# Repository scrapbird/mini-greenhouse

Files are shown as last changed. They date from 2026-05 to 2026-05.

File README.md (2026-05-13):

# mini-greenhouse

Greenhouse cabinet for the yard. 2m W × 1.8m H × 0.7m D. Timber frame, polycarbonate cladding, slatted raised floor, double doors, vent hatch in roof.

Plans drafted in **FreeCAD**, with Claude Code assisting via the [`freecad-mcp`](https://github.com/neka-nat/freecad-mcp) MCP server.

See `CLAUDE.md` for locked specs and conventions.

---

## Setup

Target: Ubuntu 25.10. Adapt paths if on another distro.

### 1. Install FreeCAD

Pick one. AppImage is recommended — it's the cleanest way to get current FreeCAD 1.x without snap quirks that complicate the MCP addon path.

**FreeCAD 1.1.1 AppImage** — installed at `~/Software/FreeCAD-1.1.1.AppImage`.

How it was installed:

```bash
mkdir -p ~/Software
wget -O ~/Software/FreeCAD-1.1.1.AppImage \
  https://github.com/FreeCAD/FreeCAD/releases/download/1.1.1/FreeCAD_1.1.1-Linux-x86_64-py311.AppImage
chmod +x ~/Software/FreeCAD-1.1.1.AppImage
```

Run it:

```bash
~/Software/FreeCAD-1.1.1.AppImage
```

Optional — make it launchable from the app menu:

```bash
~/Software/FreeCAD-1.1.1.AppImage --appimage-extract-and-run --install
```

Alternatives (skip — AppImage already done):
- `sudo apt install freecad` — older version, fine if AppImage breaks
- `sudo snap install freecad` — works but uses `~/snap/freecad/common/Mod/` for addons

### 2. Install the `freecad-mcp` addon

```bash
git clone https://github.com/neka-nat/freecad-mcp.git ~/src/freecad-mcp
```

Copy the addon into FreeCAD's `Mod/` directory. Path depends on how you installed FreeCAD:

For our setup (FreeCAD 1.1 AppImage):

```bash
mkdir -p ~/.local/share/FreeCAD/v1-1/Mod/
cp -r ~/src/freecad-mcp/addon/FreeCADMCP ~/.local/share/FreeCAD/v1-1/Mod/
```

Other install methods would use different Mod paths: `~/.FreeCAD/Mod/` for older Ubuntu builds, `~/snap/freecad/common/Mod/` for snap.

Restart FreeCAD. From the Workbench dropdown pick **MCP Addon**, then **Start RPC Server** from the FreeCAD MCP toolbar. Tick **Auto-Start Server** if you want it on every launch.

### 3. `uvx` (Python tool runner)

Already installed on this machine (`/home/user/.local/bin/uvx`). If you ever need it elsewhere:

```bash
curl -LsSf https://astral.sh/uv/install.sh | sh
```

### 4. Wire the MCP server into Claude Code

From the project directory:

```bash
cd ~/Development/mini-greenhouse
claude mcp add freecad -- uvx freecad-mcp
```

This writes a `.mcp.json` in the project so the server is available whenever Claude Code runs here. Verify with:

```bash
claude mcp list
```

FreeCAD must be running with the RPC server started before Claude can talk to it.

### 5. Smoke test

In Claude Code, with FreeCAD open and the RPC server started, ask: *"Create a new FreeCAD document called `greenhouse` and add a 2000×700×1800 box as a placeholder envelope."* If the box appears in FreeCAD, the loop is working.

---

## Repo layout (will fill in as we go)

```
mini-greenhouse/
├── CLAUDE.md           # Specs + conventions for Claude
├── README.md           # This file
├── Greenhouse.FCStd    # FreeCAD model (canonical = closed state)
├── macros/             # FCMacros — open/close toggles
├── notes/              # Cut list + decisions
└── drawings/           # Exported PDFs (later)
```

## Open / close toggle

Two macros in `macros/` toggle the doors + roof hatch between closed and open states. They read all geometry from the `Dims` spreadsheet, so they stay in sync if you change posts/depth/etc.

- `gh_open.FCMacro` — swings doors out 90°, lifts hatch 60°, deploys the prop
- `gh_close.FCMacro` — reverses all of the above

To make them appear in FreeCAD's **Macro → Macros…** menu, symlink them into FreeCAD's macro dir:

```bash
ln -s ~/Development/mini-greenhouse/macros/gh_open.FCMacro ~/.local/share/FreeCAD/Macro/
ln -s ~/Development/mini-greenhouse/macros/gh_close.FCMacro ~/.local/share/FreeCAD/Macro/
```

Then in FreeCAD: **Macro → Macros…**, pick one, Execute. Or run via the FreeCAD Python console:

```python
exec(open("/home/user/Development/mini-greenhouse/macros/gh_open.FCMacro").read())
```

Macros are idempotent — running `gh_open` twice is a no-op (it detects the `Hatch_Prop` object).

---

---

## Materials

Prices NZD, rough Mitre 10 NZ ballparks — Mitre 10 NZ doesn't publish online pricing; confirm in-store.

> **Future Claude: foundation (pavers + sand) is NOT in the build budget — sourced separately. Do not add it back to subtotals or "Total estimate". Foam profile fillers for the corrugated roof are also out — the user doesn't need an airtight roof. Don't reintroduce them.**

Detailed cut list with per-product links: see [notes/cut-list.md](notes/cut-list.md).

### Timber

H3 = above-ground outdoor treated. H4 = ground-contact treated. Treated radiata pine: cheap, everywhere, rated for outdoor weather, takes stain well.

| Use | Stock | Why |
|---|---|---|
| 4× corner posts | **70×45 H3 SG8 KD pine** | Carries shelf loads + door weight. 70mm depth gives hinge screws bite. |
| Frame rails, rafters, door frames, shelf battens, back centre beam | **70×35 H3 SG8 pine** | Cheaper + lighter than 70×45. Plenty for this span. |
| Floor bearers (under cabinet, on pavers) | **90×45 H4 wet SG8 pine** | Ground-contact — first thing to rot if you skimp. |
| Floor slats + shelf slats | **90×21 H3 radiata decking** | Pre-milled smooth top, wet-duty rated. (Mitre 10 NZ stock is 90×21, not 90×19.) |

Qty + cost (2.4m lengths):

- 4× 70×45 H3 → ~$64
- 18× 70×35 H3 → ~$198
- 2× 90×45 H4 → ~$40
- 12× 90×21 decking → ~$216

**Timber subtotal: ~$518**

Why higher than first sketch: pallet-style shelves use 4 long 70×35 battens + 28 short 90×21 slats. That alone is ~9 extra lengths of timber.

### Polycarbonate

| Type | Pros | Cons | Best use |
|---|---|---|---|
| **Corrugated (Sunclear / Suntuf)** | Cheap, purpose-built for roofing, sheds water naturally, easy to screw with cap screws | Profile only suits roofs/walls with same profile; needs foam closure under ridges | **Roof** ✓ |
| **Twinwall (Ampelite, 6mm)** | Insulating air gap = warmer greenhouse, light-diffusing, externally flat, cheaper than solid | Channels need taping/closing at cut ends; not crystal-clear | **Sides + back + doors** ✓ |
| **Solid clear sheet (2–3mm)** | Crystal-clear, premium look | ~2× price of twinwall, no insulation, scratches show | Skip for this build |

Recommendation: **corrugated roof + twinwall everywhere else.**

- 1× Sunclear corrugated 2.4m clear → ~$40
- 2× Ampelite twinwall 1050×2500mm clear (back + side + door panels cut from these) → ~$140
- Aluminium U-channel edging (3 × 1m) for cut twinwall ends → ~$25

**Polycarbonate subtotal: ~$205**

### Foundation (sourced separately, NOT in build budget)

**6× 400×400×40mm concrete pavers, levelled on a sand bed, with H4 bearers spanning across them.**

- Cheap, no concreting, fully removable
- Lifts timber clear of wet ground
- Forgiving of slight ground unevenness — just rake sand flat
- Footprint: pavers overhang cabinet front and back by ~178mm each side (front overhang doubles as a doorstep)

Skip: concrete piers (overkill, permanent), galvanised post stirrups (overkill, $$$), direct-on-ground (rot bomb).

- 6× 400×400 pavers @ ~$8 → ~$48
- 1× paving sand 20kg → ~$8

*Excluded from build cost — user is sourcing pavers + sand separately.*

### Door hardware

Pattern: **inactive door (left) bolted top+bottom**, acts as a fixed jamb when shut. **Active door (right) latches** against the inactive leaf's astragal. Astragal strip on inactive leaf seals the meeting edge.

| Item | Count | Price |
|---|---|---|
| Tee-hinges, 150mm galvanised (face-mount, no rebating) | 3 per leaf × 2 = 6 | ~$108 |
| 100mm barrel bolts (inactive leaf top + bottom into roof frame and floor) | 2 | ~$30 |
| D-type gate latch (active leaf) | 1 | ~$18 |
| Handles | 2 | ~$10 (or $0 if drilled finger-pulls) |

**Door hardware subtotal: ~$166**

### Hatch hardware

Hatch hinges along the back ridge, lifts at front. Two hook-and-eye latches at front-left and front-right pin it shut against wind lift. A telescopic window stay holds it open at multiple angles.

| Item | Count | Price |
|---|---|---|
| Butt hinges 50mm zinc — corner+corner+middle along back ridge | 3 (buy 2× 2-pack) | ~$20 |
| Hook & eye latches 100mm (2-pack) | 1 pack | ~$10 |
| Telescopic window stay (multi-position) | 1 | ~$20 |

**Hatch hardware subtotal: ~$50**

### Fasteners

- Otter Treated Pine Screws 10g × 65mm, pack of 500 (frame joints — must be treated-pine rated for H3/H4 stock) → ~$45
- Otter Heavy Duty Timber Screws 14g × 50mm, pack of 100 (slats, trims) → ~$22
- Otter Polycarbonate Roof Screws 12g × 50mm, pack of 50 → ~$25
- 4–6× Zenith corner brace brackets, zinc plated → ~$25
- Aluminium U-channel 20×20×1.5mm × 2.4m (twinwall edges) → ~$25

**Fasteners subtotal: ~$142**

### Finish

Water-based decking stain (DECKMAX or Wattyl — Cabot's range is limited at Mitre 10 NZ). Apply two coats after assembly, before fitting polycarbonate.

- 10L water-based decking stain — Honey Oak or similar dark tone → ~$100 (overkill for this build; if 5L sold in-store, halve)
- Brushes (75mm + small) → ~$15

**Finish subtotal: ~$115**

### Shelves

**Timber cleats** screwed into the inner faces of the side walls — one continuous batten per height per side, shelf sits on top. 5 height positions, first at 475mm from frame bottom, 175mm spacing (last at 1175mm). 2 pallet-style shelves fitted at positions 3 and 5; can be moved.

Cleats: 20×15mm offcuts of 70×35 stock, full depth (560mm). 10 cleats total → free from frame offcuts.

Each shelf: 2× 70×35 cross-battens (1910mm long) + 14× 90×21 decking slats (560mm each) screwed on top with ~50mm gaps. Drains like the floor.

**Shelf cost: ~$0** beyond timber already counted.

### Total estimate

| | NZD |
|---|---|
| Timber | 518 |
| Polycarbonate | 205 |
| Door hardware | 166 |
| Hatch hardware | 50 |
| Fasteners | 142 |
| Finish | 115 |
| **Subtotal** | **~$1,196** |

Foundation (~$56) sourced separately, not in this subtotal. Levers to claw back, with quantified savings and running build cost if applied in order:

| # | Lever | Saves | Build cost after |
|---|---|---|---|
| 0 | (baseline) | — | $1,196 |
| 1 | Drop to 1 shelf (2 fewer battens @ ~$11 + 14 fewer decking slats @ ~$5.20) | $95 | $1,101 |
| 2 | 5L stain instead of 10L | $50 | $1,051 |
| 3 | Untreated pine for shelf slats (under roof, less weather) | $60 | $991 |
| 4 | Corrugated for back panel (replace twinwall sheet) | $50 | $941 |
| 5 | Skip aluminium U-channel; foil-tape twinwall ends + timber trim | $25 | $916 |
| 6 | Mix Marketplace / TradeMe offcuts for posts + bearers | $80+ | $836 |

Realistic floor with all levers applied: **~$836 NZD** (materials only).

---

## Tools

Detailed list with prices + ALoT (Auckland Library of Tools) borrow plan: see [tools.md](tools.md).

Owned: hand saw, cordless drill. Buying only consumables + PPE + a few daily-use measuring tools. Borrowing everything else (router, pocket-hole jig, circular saw, mitre saw, sander, clamps, levels, workbench) from ALoT half-yearly membership ($60).

| Path | NZ$ |
|---|---|
| **Borrow-max:** must-buy ($205) + ALoT half-year ($65) | **~$270** |
| + keep pocket-hole jig | ~$350 |
| + keep jig + router | ~$500 |

Default for grand total below: **borrow-max ~$270**.

Skills + YouTube tutorials: see [study_guide.md](study_guide.md).

---

## Grand total (materials + tools)

| | NZD |
|---|---|
| Materials | ~$1,196 |
| Tools (borrow-max — see Tools section) | ~$270 |
| **Project total** | **~$1,466** |

Foundation (pavers + sand, ~$56) sourced separately — not included.

Other tool paths shift the total: + jig keep = ~$1,546, + jig + router keep = ~$1,696.

With all material levers applied (see Materials → Total estimate) + borrow-max tools: could land **~$1,106 all-in** ($836 materials + $270 tools).

---

## Open questions

Still need a call on:

- Pre-stain timber before assembly, or after? (before = no missed spots; after = easier touchup)
- Floor anchoring method — depends on final site (lawn / paver / concrete)
- Stop-grooves (stub tenon) vs through-grooves on door rails — practise both, pick easier
- Future woodworking projects? — decides whether to keep (buy) jig + router (+$275) vs return after build

Resolved:

- ~~Site orientation~~ → doors face afternoon sun (west)
- ~~Tools: buy vs borrow~~ → borrow-max via ALoT half-yearly; revisit jig/router purchase if used after this build
- ~~Door panel join~~ → routed grooves (router borrowed from ALoT)

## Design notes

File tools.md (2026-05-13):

# Tools — Mitre 10 NZ + ALoT

All prices NZD, mitre10.co.nz as of 2026-05-12. Confirm at checkout.

**You already own:** hand saw, cordless drill.

Strategy: **only buy** consumables, PPE, and the few tools you'll use every day. **Borrow everything else from ALoT** — including router and pocket-hole jig if you'd only use them on this project.

---

## Already owned — skip

- Hand saw
- Cordless drill

---

## Must buy — non-borrowable

Personal/consumable items you can't (or shouldn't) share.

| Tool | Pick | NZ$ | Why must-buy |
|---|---|---|---|
| Pocket-hole screws (mixed 32+38mm) | Fuller 200-pack | $30 | Consumable |
| Drill bit set HSS | Bosch HSS 19pc 1–10mm | $45 | Personal kit, wears |
| Pozi driver bits + spares | mixed pack | $10 | Wears |
| Counter-sink bit | Stanley | $15 | Small, wears |
| Tape measure 8m | Stanley Tylon 8m | $17 | Daily use, yours |
| Combination square 300mm | Number 8 | $10 | Daily use, cheap |
| Pencils + marker + utility knife | Stanley | $20 | Daily / consumable |
| Safety glasses | Esko clear | $8 | PPE, fit/hygiene |
| Dust mask P2 (5-pack) | 3M 8210 | $25 | PPE, consumable |
| Hearing protection | Safety Extra earmuffs | $25 | PPE, fit/hygiene |

**Must-buy subtotal: ~$205**

---

## Optional buys — keep long-term, or borrow

| Tool | If buying NZ$ | Decision |
|---|---|---|
| Pocket-hole jig (Fuller, M10) | $80 | Buy if you'll do more woodworking. Otherwise borrow from ALoT |
| Router 1/4" + 6mm straight + slot bit | $150 (Ryobi + bits) | Same — buy if keeper, borrow if one-off |
| Bar clamps 300mm × 2 (cheap pair) | $45 | Buy 2 cheap, borrow extras from ALoT |

**If buying all three: +$275.**

---

## Borrow from ALoT 🅑

All borrowable; ALoT membership covers them.

| Tool | If buying NZ$ |
|---|---|
| 🅑 Circular saw 165mm | $60–280 |
| 🅑 Sliding compound mitre saw | $250 |
| 🅑 Random orbital sander | $80 |
| 🅑 Router + bits | $150 |
| 🅑 Pocket-hole jig | $80 |
| 🅑 Bar clamps (3+) | $60+ |
| 🅑 Spirit level 600mm | $16 |
| 🅑 Speed square / rafter square | $20 |
| 🅑 Bevel gauge / sliding T-bevel | $25 |
| 🅑 Long straight edge 1.2m+ | $30 |
| 🅑 Workbench / Workmate | $120 |
| 🅑 Sawhorses × 2 | $100 |

**Total avoided buys if you borrow all: ~$990+** — well worth the $60 membership.

> Verify ALoT inventory before joining. Browse: https://aucklandlibraryoftools.myturn.com/

---

## Consumables (already in materials budget — listed for completeness)

| Item | NZ$ |
|---|---|
| Cap screws + EPDM washers — corrugated poly (50-pack) | ~$25 |
| Cap screws + neoprene washers — twinwall (50-pack) | ~$25 |
| Aluminium U-channel for twinwall bottom edge (per m) | ~$8/m |
| Breathable foil tape for twinwall top edge (10m roll) | ~$30 |
| Stainless 8g×50 screws (200-pack) | ~$25 |
| Stainless 8g×75 screws (100-pack) | ~$25 |
| Exterior wood glue (Selleys Aquadhere Exterior 250ml) | ~$15 |
| Outdoor timber oil (4L) | ~$60 |
| Brushes (2-pack 50mm) | ~$10 |

---

## Auckland Library of Tools (ALoT)

**Address:** Newton/Grey Lynn, Auckland. **Site:** https://www.aucklandlibraryoftools.com/

**Membership:**

| Tier | Regular | Concession (student/CSC/gold card) |
|---|---|---|
| Monthly | $45 | $30 |
| Half-yearly | $60 | $45 |
| Annual | $105 | $75 |

**How it works:**
- Up to **10 tools at a time**
- Default loan: **7 days** (4 days on high-demand items)
- Most tools free with membership; some small per-loan charge
- Battery tools: +$1/loan
- Volunteer-run, non-profit, since 2019
- Browse inventory: https://aucklandlibraryoftools.myturn.com/

**Recommended path for this build:**
1. **Half-yearly $60** covers build window with slack.
2. Pre-check inventory online (router + jig + circular saw + mitre saw + sander + clamps).
3. Plan ALoT trips in batches — 10 tools per loan, 7 days each.

---

## Three honest tool-spend paths

| Path | What you buy | NZ$ |
|---|---|---|
| **Borrow-max** | Must-buy ($205) + ALoT half-year ($60 + ~$5 loan fees) | **~$270** |
| **+ keep jig** | Above + pocket-hole jig ($80) | **~$350** |
| **+ keep jig + router** | Above + Ryobi router ($150) | **~$500** |

Recommended: **borrow-max ~$270** unless you know you'll do more woodworking. Router + jig are the two biggest line items and both are well-stocked at ALoT.

---

## Where to shop

- **Mitre 10 NZ:** https://www.mitre10.co.nz/
- **Bunnings NZ:** https://www.bunnings.co.nz/ — Kreg jigs stocked here
- **Facebook Marketplace / TradeMe** — used drill kits, clamps
- **Hireace / Hirepool** — backup if ALoT doesn't have what you need
- **ALoT** — see above

---

## Open questions (tools-side)

- Borrow router + jig (~$270 total path) **or** buy them for future projects (~$500 total)? Depends on what comes after this build

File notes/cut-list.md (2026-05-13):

# Cut list

Generated from FreeCAD model. Bin-packed at 2.4m stock lengths, 3mm kerf per cut.

Product links → Mitre 10 NZ (mitre10.co.nz). Prices are NZD estimates only — Mitre 10 NZ doesn't publish online pricing; confirm at your local store.

## Stock summary

| Stock | Pieces | 2.4m lengths | Est. price/length | Subtotal |
|---|---|---|---|---|
| 70×45 H3 SG8 KD pine (posts) | 4 | 4 | ~$16 | ~$64 |
| 70×35 H3 SG8 KD pine (frame/doors/shelves/roof) | 27 | 18 | ~$11 | ~$198 |
| 90×45 H4 wet SG8 pine (floor bearers) | 2 | 2 | ~$20 | ~$40 |
| 90×21 H3 radiata decking (floor + shelf slats) | 33 | 12 | ~$18 | ~$216 |

**Timber subtotal: ~$518 NZD**

Cleats + astragal: rip from 70×35 offcuts (no extra stock). Decking is 90×21 at Mitre 10 NZ (closest to model's 90×19 — 2mm thicker, negligible).

## 70×45 H3 SG8 KD pine — [Mitre 10 product](https://www.mitre10.co.nz/shop/building-hardware/timber/structural-framing/structural-framing/radiata-sg8-h3-kd-70x45mm-140x45mm/c/RC61070)

| Piece | Length |
|---|---|
| Frame_PostBL | 1719mm |
| Frame_PostBR | 1719mm |
| Frame_PostFL | 1569mm |
| Frame_PostFR | 1569mm |

**4 pieces, 4 × 2.4m lengths** (1 post per length).

## 70×35 H3 SG8 pine — [Mitre 10 timber category](https://www.mitre10.co.nz/shop/building-hardware/timber/structural-framing/c/RS4105)

| Piece | Length | Count |
|---|---|---|
| Frame_EaveFront | 1930mm | 1 |
| Frame_RailBot{Front,Back}, Frame_RailTopFront, Frame_RailTopBack | 1910mm | 4 |
| Frame_RidgeBack | 1930mm | 1 |
| Shelf{2,3}_Batten{Front,Back} | 1910mm | 4 |
| Frame_BackCenter | 1700mm | 1 |
| Door{L,R}_Stile{Hinge,Latch} | 1426mm | 4 |
| Door{L,R}_Rail{Top,Bot} | 882mm | 4 |
| Frame_Rafter{Left,Right,Center} | 838mm | 3 |
| Frame_RailTop{Left,Right} | 573mm | 2 |
| Frame_RailBot{Left,Right} | 560mm | 2 |
| Frame_FloorCenter | 630mm | 1 |

**27 pieces, 18 × 2.4m lengths.**

Packing:
- 2 × (1930 + 470 offcut) — eave purlin + ridge purlin
- 8 × (1910 + 490 offcut) — perimeter rails + shelf battens
- 1 × (1700 + 573 + 127 offcut)
- 4 × (1426 + 882 + 92 offcut)
- 1 × (838 + 838 + 560 + 164 offcut) — rafters L+R + side bot rail
- 1 × (838 + 630 + 573 + 359 offcut) — **rafter Center + floor centre + side top rail**
- 1 × (560 + 1840 offcut) — side bot rail #2 (large offcut → cleats/astragal stock)

## 90×45 H4 wet SG8 pine — [Mitre 10 product](https://www.mitre10.co.nz/shop/building-hardware/timber/structural-framing/structural-framing/wet-radiata-sg8-h4-90x45mm/c/RC61520)

| Piece | Length |
|---|---|
| Foundation_BearerFront | 2000mm |
| Foundation_BearerBack | 2000mm |

**2 pieces, 2 × 2.4m lengths.**

## 90×21 H3 radiata decking — [Radiata Premium Grade Smooth Decking 90 × 21mm](https://www.mitre10.co.nz/shop/radiata-premium-grade-smooth-decking-90-x-21mm/p/635401)

| Piece | Length | Count |
|---|---|---|
| Floor_Slat{1..5} | 1930mm | 5 |
| Shelf{2,3}_Slat{01..14} | 560mm | 28 |

**33 pieces, 12 × 2.4m lengths.**

Packing:
- 5 × (1930 + 470 offcut)
- 7 × (4 × 560 + 151 offcut)

## From offcuts (no extra stock)

- **10 × shelf cleats** @ 560mm × 20×15mm — rip from 70×35 offcuts (~6m of cleat needed; one 2.4m of 70×35 ripped yields ~14m of 20×15 strips)
- **1 × astragal** @ 1497mm × 30×12mm — rip from a 1910 offcut

# Polycarbonate panels

| Panel | W × H (mm) | Buy product |
|---|---|---|
| Roof_Hatch | 2000 × 822 | [Sunclear Ultra Corrugated 2.4m Clear](https://www.mitre10.co.nz/shop/sunclear-ultra-corrugated-polycarbonate-2-4m-clear/p/335668) (cut to 822mm width from 860mm sheet) |
| Panel_BackL, Panel_BackR | 1630 × 930 | [Ampelite Twinwall Glazing 1050 × 2500mm Clear](https://www.mitre10.co.nz/shop/ampelite-twinwall-polycarbonate-glazing-system-1050-x-2500mm-clear/p/128788) (one sheet cuts two back panels) |
| Panel_Left, Panel_Right | 1650 × 630 | Cut from the same back-panel sheet's offcut, or [Ampelite 1220 × 610mm Clear](https://www.mitre10.co.nz/shop/ampelite-twinwall-polycarbonate-sheet-1220mm-x-610mm-clear/p/286867) (×2 — but undersize, would need larger) |
| DoorL_Infill, DoorR_Infill | 1427 × 882 | Cut from a 1050 × 2500mm sheet (1 more sheet needed) |

**Polycarb estimate**:
- 1 × Sunclear corrugated 2.4m: ~$40
- 2 × Ampelite twinwall 1050×2500: ~$70 each = ~$140
- Total: ~**$180 NZD**

Side panels are 5-sided: cut as rectangle, then trim the upper edge to follow roof slope (~12° from horizontal).

# Hardware

## Door hardware

| Item | Count | Product | Est. NZD |
|---|---|---|---|
| Tee-hinges (face-mount on front) | 3 per door × 2 doors = 6 | [Gator Heavy Duty Tee Hinge 150mm Galvanised](https://www.mitre10.co.nz/shop/gator-heavy-duty-tee-hinge-150mm-galvanised/p/384426) | ~$18 each → ~$108 (or buy 2-packs if cheaper per-unit) |
| 100mm barrel bolts (inactive leaf top + bottom) | 2 | [Zenith Necked Barrel Bolt 100mm](https://www.mitre10.co.nz/shop/zenith-necked-barrel-bolt-100mm/p/205383) | ~$15 each → ~$30 |
| Gate latch (active leaf) | 1 | [Gartner D Type Gate Latch 170mm Galvanised](https://www.mitre10.co.nz/shop/gartner-d-type-gate-latch-170mm-galvanised/p/374863) | ~$18 |
| Cabinet pulls / handles | 2 | Generic pull or drilled finger-pull | ~$10 (or $0 if drilled) |

## Hatch hardware

| Item | Count | Product | Est. NZD |
|---|---|---|---|
| Butt hinges (back ridge — corner+corner+middle) | 3 (buy 2× 2-pack) | [Zenith Easy Fit Hinges 50mm Zinc Plated](https://www.mitre10.co.nz/shop/zenith-easy-fit-hinges-50mm-zinc-plated/p/209101) | ~$20 (2× 2-pack) |
| Casement window stay (multi-position) | 1 | [Jaeco Telescopic Window Stay 278mm](https://www.mitre10.co.nz/shop/jaeco-telescopic-window-stay-278mm-satin-chrome-finish/p/214252) | ~$20 |
| Hook & eye latches (front corners) | 2 | [Zenith Gate Hook & Eye 100mm — 2 Pack](https://www.mitre10.co.nz/shop/zenith-gate-hook-eye-zinc-plated-100mm-2-pack) | ~$10 (2-pack covers both) |

## Foundation (sourced separately — NOT in build budget)

| Item | Count | Product | Est. NZD |
|---|---|---|---|
| 400×400×40mm concrete pavers | 6 | [Premier Flagstone Paver 400×400×40mm](https://www.mitre10.co.nz/shop/premier-flagstone-paver-400-x-400-x-40mm-iron-sand/p/202882) | ~$8 each → ~$48 |
| Paving sand | 1 bag | [Paving Sand 20kg](https://www.mitre10.co.nz/shop/paving-sand-20kg/p/2023381) | ~$8 |

*Future Claude: don't add this to subtotals — user sources separately.*

## Fasteners

| Item | Pack | Product | Est. NZD |
|---|---|---|---|
| 65mm timber screws (frame) | 1 pack (~100 needed) | [Otter Treated Pine Screws 10g × 65mm — Pack of 500](https://www.mitre10.co.nz/shop/otter-treated-pine-screws-10g-x-65mm-pack-of-500-galvanised/p/327993) (treated-pine rated, important for H3/H4 stock) | ~$45 |
| 50mm timber screws (slats, trims) | 1 pack (~50 needed) | [Otter Heavy Duty Timber Screws 14g × 50mm — Pack of 100](https://www.mitre10.co.nz/shop/otter-heavy-duty-timber-screws-14g-x-50mm-pack-of-100-galvanised/p/231194) | ~$22 |
| Polycarbonate roof screws | 1 pack (~40 needed) | [Otter Polycarbonate Roof Screws 12g × 50mm — Pack of 50](https://www.mitre10.co.nz/shop/otter-polycarbonate-roof-screws-12g-x-50mm-pack-of-50-galvanised/p/231773) | ~$25 |
| Corner brace brackets | 4–6 | [Zenith Corner Brace Bracket](https://www.mitre10.co.nz/shop/zenith-corner-brace-bracket/p/220106) | ~$5 each → ~$25 |
| Aluminium U-channel (twinwall edges) | 3 × 1m or 1 × 2.4m | [Metal Mate Aluminium Channel 20 × 20 × 1.5mm × 2.4m](https://www.mitre10.co.nz/shop/metal-mate-aluminium-channel-20x20x1-5mm-x-2-4m-silver/p/372583) | ~$25 |

**Fasteners subtotal: ~$142 NZD**

*Future Claude: foam eave filler under corrugations is intentionally excluded — user doesn't need an airtight roof. Don't add it back.*

## Finish

| Item | Size | Product | Est. NZD |
|---|---|---|---|
| Water-based decking stain | 10L | [Water Based Decking Stain 10L Honey Oak](https://www.mitre10.co.nz/shop/water-based-decking-stain-10l-honey-oak/p/278680) (10L is overkill — confirm if 5L sold in-store) | ~$100 |
| Brushes (75mm + small) | — | Generic brushes | ~$15 |

**Finish subtotal: ~$115 NZD**

# Total estimate (NZD)

| | NZD |
|---|---|
| Timber | 518 |
| Polycarbonate | 205 |
| Door hardware | 166 |
| Hatch hardware | 50 |
| Fasteners | 142 |
| Finish | 115 |
| **Subtotal** | **~$1,196** |

Foundation (~$56 in pavers + sand) sourced separately, **not** in this subtotal. Foam roof eave filler also excluded — user doesn't need an airtight roof.
- README under-counted hardware (tee-hinges, stay, brackets).

Levers to claw back:
- Drop one shelf (already at 2; could go to 1 to halve shelf timber).
- Use 90×19 untreated for shelf slats, finished with stain (cheaper, less rot-resistant — OK if shelves don't see direct rain).
- Buy 5L stain, not 10L (~$50 saved).
- Use smaller polycarb sheet sizes — e.g. corrugated for the back too (cheaper than twinwall).

# Joinery summary

All joints butt + screw. No mortice/tenon, no halving. Pocket screws optional for door frames if a Kreg jig is borrowable.

Critical joint locations:
- Posts ↔ bottom rails: 2 × 65mm screws toe-nailed through rail end into post end-grain. Add corner brace.
- Posts ↔ top rails: same.
- Top rails ↔ rafters: rafters sit on top of front + back top rails. 2 screws each end through rafter into rail.
- Door frame stiles ↔ rails: pocket screws (preferred) OR 2 × 65mm through stile face into rail end. Glue.
- Bearers ↔ bottom rails: 4–5 × 65mm screws up through bearer into bottom rail.
- Centre back beam ↔ top/bottom rails: butt + 2 × 65mm screws each end.
- Cleats ↔ side panels/posts: 3 × 50mm screws per cleat through side panel into post (front+back+middle).
- Tee-hinges: through hinge plate into door stile (front face) + post (front face).

# Sources

- [Pine Products at Mitre 10](https://www.mitre10.co.nz/trade/suppliers/pine-products)
- [Mitre 10 timber category](https://www.mitre10.co.nz/shop/building-hardware/timber/c/RD1001)
- [Mitre 10 structural framing](https://www.mitre10.co.nz/shop/building-hardware/timber/structural-framing/c/RS4105)
- [Mitre 10 decking timber](https://www.mitre10.co.nz/shop/building-hardware/timber/decking-timber/c/RS4108)
- [Mitre 10 roofing polycarbonate](https://www.mitre10.co.nz/shop/building-hardware/building-supplies/roofing/roofing/roofing-polycarbonate/c/RC42630)
- [Mitre 10 pavers & blocks](https://www.mitre10.co.nz/shop/building-supplies/concrete-metal-products/pavers-blocks/c/RF5051)
- [Mitre 10 hinges](https://www.mitre10.co.nz/shop/building-hardware/hardware/gate-fence-hardware/hinges/c/RF7146)
- [Mitre 10 window stays](https://www.mitre10.co.nz/shop/building-hardware/hardware/windows/window-stays/c/RF7395)
- [Mitre 10 fasteners](https://www.mitre10.co.nz/shop/building-hardware/hardware/fasteners-fixing/screws/general-timber-screws/c/RC19300)
- [Mitre 10 exterior stains & oils](https://www.mitre10.co.nz/shop/paint-decorating/paint/exterior-paint/exterior-stains-oils/c/RF7097)

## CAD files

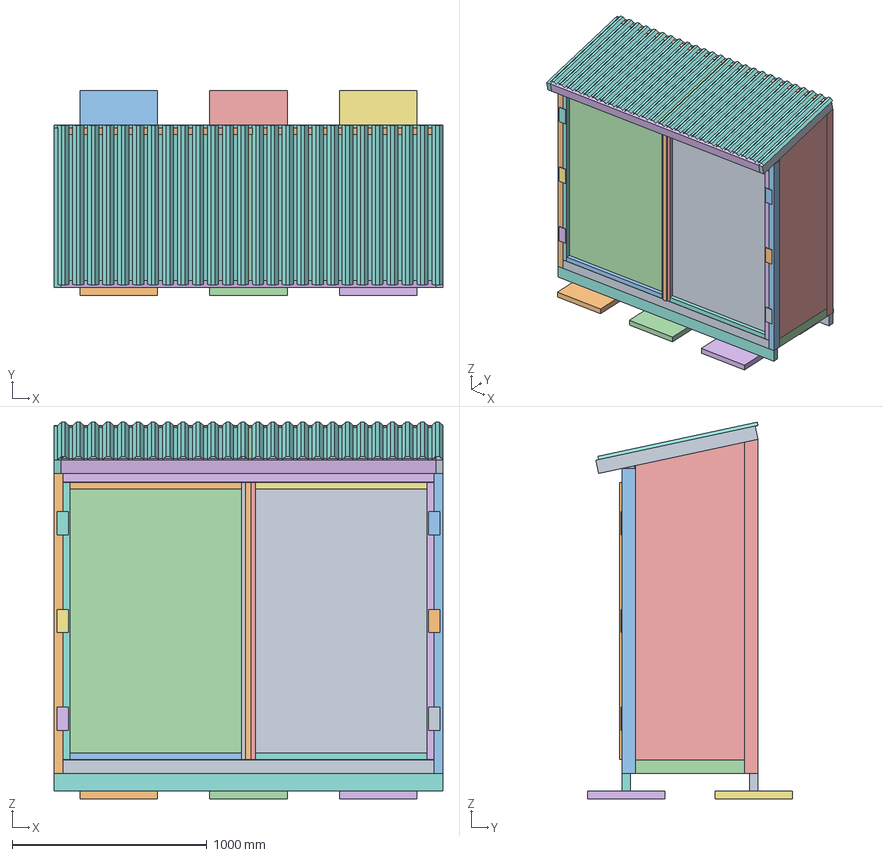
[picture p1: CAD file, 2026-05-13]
Greenhouse.FCStd
2000.0 x 1055.0 x 1936.8 mm
Frame_RailBotFront
Frame_RailBotBack
Frame_RailBotLeft
Frame_RailBotRight
Shelf_CleatL2
Shelf_CleatR2
Shelf_CleatL3
Shelf_CleatR3
Shelf_CleatL4
Shelf_CleatR4
Shelf_CleatL5
Shelf_CleatR5
Shelf_CleatL6
Shelf_CleatR6
Hatch_LatchL
Hatch_LatchR
Shelf2_BattenFront
Shelf2_BattenBack
Shelf2_Slat01
Shelf2_Slat02
Shelf2_Slat03
Shelf2_Slat04
Shelf2_Slat05
Shelf2_Slat07
Shelf2_Slat08
Shelf2_Slat09
Shelf2_Slat10
Shelf2_Slat11
Shelf2_Slat12
Shelf2_Slat13
Shelf2_Slat14
Foundation_BearerFront
Foundation_BearerBack
Foundation_Paver1F
Foundation_Paver1B
Foundation_Paver2F
Foundation_Paver2B
Foundation_Paver3F
Foundation_Paver3B
Roof_Hatch
Shelf3_BattenFront
Shelf3_BattenBack
Shelf3_Slat01
Shelf3_Slat02
Shelf3_Slat03
Shelf3_Slat04
Shelf3_Slat05
Shelf3_Slat06
Shelf3_Slat07
Shelf3_Slat08
Shelf3_Slat09
Shelf3_Slat10
Shelf3_Slat11
Shelf3_Slat12
Shelf3_Slat13
Shelf3_Slat14
Floor_Slat1
Floor_Slat2
Floor_Slat3
Floor_Slat4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

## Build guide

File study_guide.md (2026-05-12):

# Study guide — mini-greenhouse build

Skills you'll touch, in roughly the order you need them. Each entry: what, why, links.

---

## 1. Measure & mark

What: pull tape, transfer dim to timber, mark cut line with square + pencil. "Measure twice, cut once" is real.

Why: every cut later inherits the error from this step.

Watch:
- [Tape measure tips for beginners](https://www.youtube.com/watch?v=Ifk7Bn5Vluc) — reading 16ths, hook is loose on purpose
- [Using a combination square](https://www.youtube.com/watch?v=2hkqe_VFOR0) — square line, mitre, marking depth

---

## 2. Crosscuts (square cuts to length)

What: 90° cut across timber. Most cuts on this build are crosscuts to length.

Tools: hand saw OR circular saw with speed square as guide.

Why: posts, rails, slats — all crosscut.

Watch:
- [Circular saw basics (beginner)](https://www.youtube.com/watch?v=R4ApY7lFqEM)
- [Using a speed square as a cut guide](https://www.youtube.com/watch?v=K8GG8FXxnGw)
- [Hand saw technique](https://www.youtube.com/watch?v=4iJKBYNJxqM) — if going manual

Tip: clamp a straight board as a fence — gives perfectly square cuts every time with circular saw.

---

## 3. Bevel cuts

What: cut with the blade tilted, not perpendicular. Used for side top rails (≈12° bevel to match roof slope) and rafter ends.

Why: side top rails need vertical ends so they sit flush against the vertical posts, but their face is sloped. So the end-cut is a bevel.

Watch:
- [Bevel cuts with a circular saw — Mr Adams](https://www.youtube.com/watch?v=gVq9n-JTowY)
- [Toolstop bevel guide](https://www.youtube.com/watch?v=veinzkhZBCA)
- [45° bevel + miter explained](https://www.youtube.com/watch?v=znQvM59Xt3c)

Tip: set the angle, cut a test piece, check with a protractor or bevel gauge before cutting your real timber.

---

## 4. Pocket-hole joinery ← **chosen method for this build**

What: drill an angled hole into one board, drive a screw through it into the next board. Strong, hidden, beginner-friendly.

Why: joining rails to posts and door-frame stiles to rails. Faster than mortise & tenon, stronger than butt-screws.

Watch:
- [Beginner's guide to pocket holes (Kreg)](https://www.youtube.com/watch?v=eLrDC0xYzQU)
- [Pocket-hole tutorial 320 jig](https://www.youtube.com/watch?v=4cGzVCcDDZA)
- [Pocket Holes 101 step-by-step](https://www.youtube.com/watch?v=bxRSbg8WAz4)
- [Kreg official "7 simple pocket-hole joints"](https://learn.kregtool.com/learn/video-7-simple-pocket-hole-joints/)

For this build: 70×45 posts and 70×35 rails — use coarse-thread screws (softwood), set jig for 35mm material thickness.

---

## 5. Drilling pilot holes

What: small-diameter hole before driving screw — prevents splitting, keeps screw straight.

Why: timber will split when screwing close to an end. Always pilot near ends, near edges, into hardwood, or with fat screws.

Watch:
- [Pilot holes — when and why](https://www.youtube.com/watch?v=qPB1aPAItuQ)

Rule of thumb: pilot ≈ 70% of screw shank diameter (so for an 8g screw ≈ 3mm bit).

---

## 6. Router work — grooved door panels ← **chosen for this build**

What: cut a groove down the inside edge of each door stile + rail so a poly panel slides in like a picture frame. Done with a plunge router + straight bit (6mm matches twinwall thickness).

Why: strong, weatherproof door without exposed fasteners on the panel. The look you wanted.

Watch:
- [Router basics — plunge router intro](https://www.youtube.com/watch?v=lXJ5rOzGoa4)
- [Cabinet door with grooved frame (router)](https://www.youtube.com/watch?v=u3qzWg8Yj-c)
- [Cutting a groove with a router & edge guide](https://www.youtube.com/watch?v=O_Lk5n3LXYM)
- [Rebate joints explained](https://www.youtube.com/watch?v=zSDgxMxIRR8)

Practical steps for this build:
1. Mark groove on inside edge of each stile + rail — centred, ~10mm deep, 6mm wide.
2. Set router bit projection to ~10mm; clamp an edge guide for offset.
3. Practise on offcuts until your test piece slips a 6mm scrap of poly in with no slop.
4. Stop the grooves on the rails before they exit the ends (stub tenon style) OR run them through and bevel the corner joint — beginner: run-through is simpler.
5. Glue + pocket-screw the frame around the poly panel — **don't glue the poly**, it needs to float for thermal expansion.

Bit & speed tips:
- Use a sharp straight bit. Cheap dull bits burn the timber.
- Multiple shallow passes (3mm each) beats one deep pass — fewer burns, less router strain.

---

## 7. Cutting polycarbonate

### Twinwall (sides, doors, back)

What: cut to size with fine-tooth blade. Seal the cut channels — top with breathable foil tape, bottom with U-channel.

Watch:
- [Multiwall installation guide](https://www.youtube.com/watch?v=H_vZHihwb98)
- [Greenhouse twinwall end-wall install](https://www.youtube.com/watch?v=lNBYQ5Bc5wg)
- [Twinwall step-by-step short](https://www.youtube.com/shorts/qxXcXI-MECQ)

### Corrugated Suntuf (roof)

What: cut along corrugations with utility knife in a valley; across corrugations with fine-tooth circular saw blade reversed (or jigsaw).

Watch:
- [Suntuf install — corrugated roofing](https://www.youtube.com/watch?v=SiTjjJtFJ24)
- [Corrugated polycarbonate roof DIY](https://www.youtube.com/watch?v=W3JMsLP2Yfc)
- [Suntuf cutting & fixing](https://www.youtube.com/watch?v=I55YdKp0Dps)

Critical:
- Oversize fixing holes by 2–3mm (poly expands ~2.5mm/m with temp swing). Don't overtighten — washer should just dimple, not crush.
- Cap screws (with EPDM/neoprene washers) go through the **ridges** of corrugated, not valleys.

---

## 8. Hanging doors with tee-hinges

What: surface-mount tee-hinge, long leaf on the door, short leaf on the post.

Watch:
- [How to fit T hinges](https://www.youtube.com/watch?v=KfSJSvPBlgE)
- [Suffolk Latch fitting guide](https://www.youtube.com/watch?v=KESjwdp7b_g)
- [Gate tee-hinges install](https://www.youtube.com/watch?v=9i7qj-7nB1Y)

Rule: top hinge 150mm down from door top, bottom hinge 150mm up from door bottom. Hang the **inactive** leaf first, shim 2–3mm clearance at top/sides, screw, then hang active.

---

## 9. Latches, barrel bolts, window stays

What:
- Inactive door: barrel bolt top + barrel bolt bottom into the rails (drilled hole catches the bolt).
- Active door: surface latch latching into the astragal on the inactive leaf.
- Hatch: window stay or arm holds it open; barrel bolt or hook+eye on each side holds it closed.

Watch:
- [Installing a barrel bolt](https://www.youtube.com/watch?v=mAYNqXkkPgs)
- [Fitting a window casement stay](https://www.youtube.com/watch?v=4VqAVc-r5lM)

---

## 10. Slatted floor

What: 12 × 90×21 H4 decking pieces, gaps for drainage, sitting on 2 × 90×45 H4 bearers.

Skill: just crosscuts to length + screwing down. Pre-drill near ends.

Tip: use 4–6mm gaps between slats (a paint stir stick is roughly 4mm — great spacer).

---

## 11. Finishing (stain / oil)

What: brush or wipe outdoor timber oil onto every face of every piece **before assembly** if you want max life. Otherwise just brush after.

Why: bare softwood outside = 2–3yr life. Oiled = 5–10yr. Polycarbonate is the weather barrier but the timber gets wet from rain hitting it.

Watch:
- [Applying decking oil](https://www.youtube.com/watch?v=Z4xK1XO8tDk)
- [Exterior timber finishing — DIY tips](https://www.youtube.com/watch?v=KEcgYJYrZJg)

---

## 12. Anchoring (toddler safety)

What: cabinet ≈110kg, but a 2m-tall structure pulled at the top by a small human can still tip. Anchor to ground or wall.

Options:
- Ground screws / earth anchors at each rear corner (best for free-standing)
- L-bracket + masonry anchor into a wall behind it
- Concrete pavers under bearers + ratchet strap over the top (cheapest)

Watch:
- [Earth anchors for sheds and greenhouses](https://www.youtube.com/watch?v=ZK2pe9ZWzZc)

---

## Order to learn / try first

1. Practise crosscuts on offcuts (lots).
2. Practise pilot + screw on offcuts.
3. Practise pocket holes on offcuts (if going that route).
4. Practise one bevel cut.
5. **Then** start cutting real stock.

The first hour of mistakes is cheap. The first cut on real timber should not be your first cut ever.

---

## Open questions (skill-side)

- Floor anchoring method — depends on final site (lawn / paver / concrete)
- Stop-grooves (stub tenon) vs through-grooves on door rails — practise both, pick easier

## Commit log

2026-05-12 initial: specs, README w/ materials+budget, FreeCAD model
    Frame 70x45 posts, 70x35 rails/rafters/door-frames. Slatted 90x19 floor.
    Active/inactive double doors w/ astragal+bolts. Hinged roof hatch.
    8-position cleat shelves, 3 fitted. Parametric off Dims spreadsheet
    where slope-independent.
    [Greenhouse.FCStd]
2026-05-12 model: shelves swapped to pallet-style 90x19 decking, 2 shelves not 3
    Pallet shelf = 2 battens (35x70 on-edge) + 14 slats (90x19) per level,
    drains like floor. Removed bottom shelf, kept positions 4 and 7 of 8.
    [Greenhouse.FCStd]
2026-05-12 model: center back beam, split back poly into two 930mm panels
    70x35 vertical beam at x=W/2, butts to underside of back top rail.
    Halves the back polycarbonate sheet size.
    [Greenhouse.FCStd]
2026-05-12 foundation + cut list; site orientation locked
    Pavers (6x 400x400) + bearers (2x 90x45 H4) added to model.
    Generated bin-packed cut list at notes/cut-list.md.
    Site orientation: doors face afternoon sun (west).
    [Greenhouse.FCStd]
2026-05-12 README + cut list: NZD/Mitre10 NZ, updated qtys, realistic budget
    Switched currency from AUD to NZD; Bunnings refs → Mitre 10 NZ.
    Quantities aligned to model: 14x 70x35, 12x 90x21 decking, 6 tee-hinges.
    Decking spec 90x19 → 90x21 (NZ stock). New budget estimate ~NZ$1,238
    (or ~$900 with cuts) vs original NZ$550 target.
2026-05-12 model: corrugated roof, opal twinwall panels
    Roof_Hatch now a 26-period trapezoidal wave (~77mm pitch, 17mm amp,
    1.2mm sheet) running down the slope. Twinwall panels shifted to opal
    colour with 55% transparency to read as twinwall instead of clear.
    [Greenhouse.FCStd]
2026-05-12 model: move top shelf down one cleat (position 7 → 6, z=1175)
    [Greenhouse.FCStd]
2026-05-12 model: clearance fixes (slats, side panels, hinges)
    - Floor slats now start at y=PostY (was RailT). Door bottom no longer
    collides with first slat; slats no longer pass through corner posts.
    - Side panels bounded y=70..630 to match side bottom rail. Top edge
    follows rafter underside plane (was 35mm above it).
    - Tee-hinges centred on post/door interface (x=15..75 left, mirrored
    right) — now bridge post + door instead of sitting only on door.
    [Greenhouse.FCStd]
2026-05-12 macros: open/close toggle, README docs
    Two FCMacros pull geometry from Dims spreadsheet, idempotent via
    Hatch_Prop presence check. gh_open swings doors 90°, lifts hatch 60°,
    adds prop+brackets. gh_close reverses. Canonical .FCStd is closed
    state — saves having to maintain parallel open/closed models.
    [Greenhouse.FCStd]
2026-05-12 model: minor save (test toggle round-trip)
    [Greenhouse.FCStd]
2026-05-12 model: fix roof frame clipping + side rail position
    - Side top rails moved x=41..76 → x=6..41 (adjacent to panel inner face,
    no more 35mm gap)
    - Rafters truncated 838 → 767mm, end at y=630 (back post inside face)
    so rotation arc clears back posts/panel
    - Back panel top + back centre beam dropped z=1720 → 1700 to clear the
    ridge purlin bottom
    [Greenhouse.FCStd]
2026-05-12 model+macros: hatch as proper single-frame lid
    - Rafters + eave + ridge + sheet all rotate as one rigid hatch unit
    - Ridge is now part of hatch (moves with sheet/rafters), positioned
    between rafter back ends at y=595..630
    - Rafters truncated to end at y=630 (back post inside face) so
    rotation arc stays clear of back posts
    - Hinge axis moved to (D, H_b) = outside back of build, per real
    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
2026-05-12 model: lower side top rails by RW perpendicular to slope
    Rafter bottom and side rail top are now coplanar (wall-plate slope),
    so the hatch rafter sits flush on top of the cabinet's side top rail
    when closed instead of phasing through it.
    [Greenhouse.FCStd]
2026-05-12 macros: idempotent open/close via absolute placements
    Both macros now compute canonical closed placements from Dims and
    SET them (not relative-rotate from current state). gh_open then
    applies open rotations on top of the reset placements. Toggle is
    now state-independent — corrupt or mixed states self-heal on next
    macro run.
    [Greenhouse.FCStd]
2026-05-12 model: lower wall plates so lid sits flush within H_ext=1800
    Cabinet wall plate top is now at slope plane minus RW perpendicular
    (H_f_wall = H_f - RW/cos ≈ 1569 front, H_b_wall ≈ 1719 back). Lid
    rafter bottom now coplanar with cabinet top — no more collision
    between hatch frame and front top rail.
    - Front posts 1640 → 1569mm
    - Back posts 1790 → 1719mm
    - Front top rail top z lowered to H_f_wall
    - Back top rail re-added at H_b_wall
    - Door height 1497 → 1426mm (lost ~70mm to make room)
    - Side panel top edge now follows wall plate slope (matches lid bottom)
    - Macros' compute_closed_placements uses H_f_wall for door positions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
    [Greenhouse.FCStd]
2026-05-12 model: bevel-cut side top rails for flush post fit
    Side top rails now have vertical end faces (at y=PostY and y=D-PostY)
    that butt flush against the vertical post faces. Top and bottom of
    rail still slope-aligned. Built as polygon extrusion instead of
    slope-rotated box.
    [Greenhouse.FCStd]
2026-05-12 model+macros: lid frame extends to back wall, hinge at H_b_wall
    Rafters re-extended to y=D=700 (length 838mm). Ridge purlin moved
    to between rafters at y=665..700 (back-bottom at cabinet back wall).
    Lid frame back-bottom now flush with cabinet back wall top (H_b_wall).
    Hinge axis lowered to (D, H_b_wall=1719) — actual back-wall-top
    position — so rotation arc is centred on where the hinge will be in
    real construction.
    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
    [Greenhouse.FCStd]
2026-05-12 model: fix latch z position + add center floor beam
    - Hatch_LatchL/R moved from z=H_f (1640) down to z=H_f_wall (1569),
    now sitting on top of front top rail instead of floating where the
    old cabinet top used to be.
    - Frame_FloorCenter: 70x35 beam down middle of cabinet (x=W/2,
    y=35..665, z=0..70) running front to back, supporting slats
    mid-span for heavy pots. Fits into existing 70x35 offcut bin —
    no extra stock.
    [Greenhouse.FCStd]
2026-05-12 model: save (post-update working state)
    [Greenhouse.FCStd]
2026-05-12 remove top 2 shelf positions, exclude foundation+foam from budget
    - Top 2 cleat positions removed (was 8, now 6 — z=300..1175). Top
    remaining shelf at z=1175 was already there; just no more empty
    cleats above it.
    - Foundation (pavers + sand, ~$56) marked as out-of-budget — user
    is sourcing separately. README + cut list have explicit notes for
    future Claude not to re-add.
    - Foam corrugated eave filler removed — user doesn't need an airtight
    roof. Saves ~$20 on fasteners. Same future-Claude note.
    - New subtotal: ~NZ$1,175 (was $1,271).
    [Greenhouse.FCStd]
2026-05-12 remove bottom shelf cleat position (too low)
    Now 5 cleat positions (z=475..1175, was 6). 10 cleats total (was 12).
    Shelves now at positions 3 (z=825) and 5 (z=1175).
    [Greenhouse.FCStd]
2026-05-12 docs: tools.md + study_guide.md, lock tool decisions
    [Greenhouse.FCStd]
2026-05-13 lid: add Frame_RafterCenter for mid-span support
    +1 70×35 838mm rafter; 17→18 stocks, +$11 timber.
    Macros + cut-list updated. Mirrors floor centre beam at x=1000.
    [Greenhouse.FCStd]
2026-05-13 hatch: remove HingeBar, switch to 3 discrete butt hinges
    [Greenhouse.FCStd]
2026-05-13 tools: honest borrow-max path; default $270 instead of $699
    Most of prior must-buy list (router, jig, clamps, levels, squares)
    is borrowable from ALoT. Strip to consumables + PPE + daily-use.
